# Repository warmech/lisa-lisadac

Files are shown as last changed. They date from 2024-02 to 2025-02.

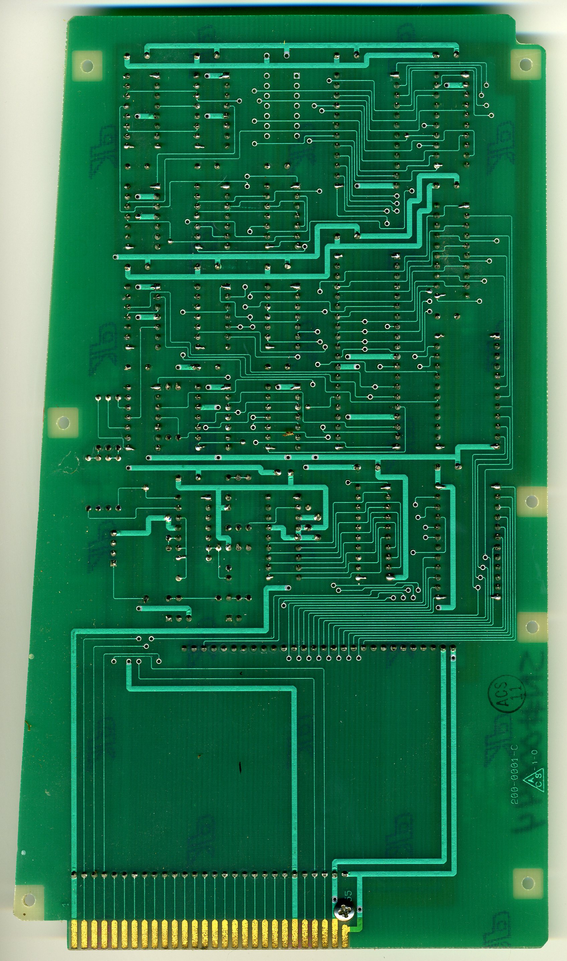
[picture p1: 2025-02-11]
neville_and_steele/NevilleAndSteele_LisaDAC_back.jpg

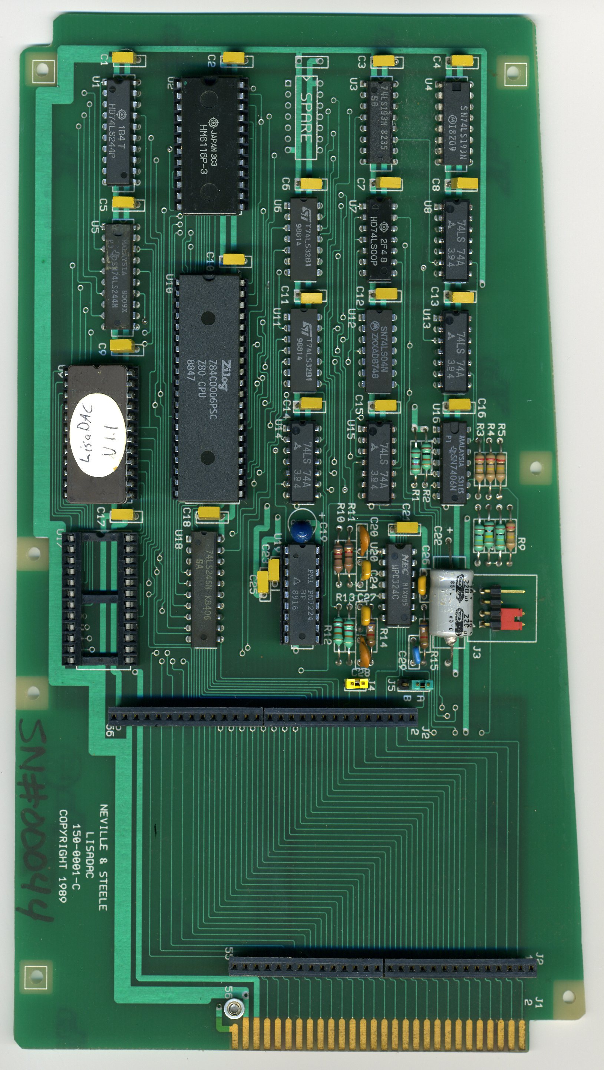
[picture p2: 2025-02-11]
neville_and_steele/NevilleAndSteele_LisaDAC_front.jpg

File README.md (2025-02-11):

# LisaDAC
 
This project aims to reproduce Neville & Steele's DAC expansion card for the Apple Lisa (via MacWorks) which provided audio functionality similar to the Macintosh sound hardware. The LisaDAC does not, however, produce 100% compatibility with Mac sound hardware and, as such, has a reduced/degraded audio output when compared to a Macintosh. In some cases, calls made in MacWorks to what would be the Mac's sound hardware when using a LisaDAC may result in MacOS/MacWorks crashing.

## Creator Commentary (10 February, 2025)

Daris A. Nevil, the original creator of this hardware, has generously provided some high-resolution scans and commentary on the history and design of this card. These can be found in the [neville_and_steele](neville_and_steele) directory in the root of this repository. Many thanks to Mr. Nevil for reaching out and providing these! It was a pleasure hearing from you.

## ROM Version

Both version 1.0 (v1_0.BIN) from the Neville & Steele card and 1.1 (v1_1.BIN) from the newer LDAC reproduction are included with this repository. These ROM dumps should be programmed on a 2716 EPROM or other compatible device.

## Jumper Settings

- J3 - Speaker Selection: To use the internal speaker, place a jumper on pins 3 and 4; to use an external speaker, connect the leads to pins 1 and 4.
- J4 - DMA Bus Grant Pass-Through: Whether or not this should have a jumper is debatable; no other Lisa expansion card uses DMA, so there aren't really any other DMA processes to interfere with. The stock configuration is to place a jumper across J4.
- J5 - Unknown: Likely has to do with card slot selection. Configuration "A" jumpers pins 1 and 2 and ties the /SHn (where n is 0, 1, or 2) line on the expansion bus to pin 9 of the 74LS00 at U7; configuration "B" jumpers pins 2 and 3 and ties the +5V rail to pin 9 of the 74LS00 at U7.

## Stability and Crashing

The LisaDAC is generally stable and does not cause stability issues in and of itself when used with a Lisa. Rather, the issue comes with Mac software making unsupported calls to the Mac's (well, MacWorks') sound hardware. StuntCopter, for instance, will run with no issues (albeit not sounding the best) until completing a successful round of five jumps. Upon completion of the fifth successful jump the victory chime is triggered; the call made to play the chime causes MacOS/MacWorks to immediately hang up, requiring either the reset button to be pressed or the Lisa's power to be cycled.

The following is a list of software with known incompatibilities with the LisaDAC:

- StuntCopter
	- Victory ("backflip") chime causes MacOS/MacWorks to crash

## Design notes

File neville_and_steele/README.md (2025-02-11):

# Neville & Steele version of LisaDAC

I have been interested in computer-generated sound at least since my freshman year in college. I began thinking about how to add sound output to my Lisa-XL computer. The Macintosh contained simple but effective four-channel sound generation. The Lisa-XL ran the same operating system, so I surmised that it might be possible to build hardware to work with the operating system software.

My friend Darryl Burrows had schematics and other technical documentation for the Lisa. After studying them I found some important features that assured my eventual success.

1. The Lisa provided three expansion slots.

2. It also supported DMA (Direct-Memory Access) from these slots to the system memory

3. The Lisa's built-in speaker was connected to each of the three slots

I designed and built a prototype circuit. It was hand-wired point-to-point. It worked well enough that I moved forward with the project. I outsourced the printed circuit board layout to a company down in Garland, Texas across Jupiter Road from Raytheon. The board layout had an unusual shape due to the sloping back of the Lisa, so it was nice to have a professional board shop do the layout and routing.

I worked with a small surplus electronics company on Bowser Road in Richardson, Texas.

Once we received the bare boards and the components, my wife Marianne and I set to work building the boards. We ordered 50 boards and enough parts to populate them all. I stuffed boards and Marianne did most of the soldering. She also debugged and repaired boards. (She can do just about anything!)

We sold about 30 of the boards. I tried to arrange to sell them through Sun Remarketing in Utah, but they were not interested. I finally contacted a company named DAFAX. They purchased the rights to the entire product. I don't know how many of them they sold, or if they made anymore boards. 
 
As you inspect the board you will notice two long connectors on the bottom half of the bottom half of the board. This is for lower-cost expansion (because making the specially shaped Lisa boards was more expensive). I designed and built a SCSI disk interface board. It leveraged the SCSI interface software that Sun Remarketing had put into the MacWorks Plus software. This may have been one of the reasons why Sun did not buy the board. They were already manufacturing a Lisa SCSI board and did not want a competitor. 

## Design

The board operated as follows. A 6116 static RAM was connected directly to the main Lisa 68000 CPU bus through the expansion connector. It served as a dual port RAM. The back half was also connected to an on-board Z80 CPU. The 68000 CPU was responsible for generating the sound values in a buffer on the RAM chip. The Z80 CPU ran a very small program that simply copied one byte at a time from the RAM and wrote it to a Digital-to-Analog Converter (DAC, hence LisaDAC). The analog output from the DAC was amplified by an LM324 operation amplifier (OPAMP) which drove the Lisa Speaker. The remainder of the TTL chips were used to control access to the 6116 static RAM between the 68000 and Z80 CPUs, as well as address decoding, etc. An on-board EPROM was also connected to the 68000 bus. It was read at power-up by the MacWorks Plus operating system to let the system know that the card was present.

A device driver was also required to be loaded in the MacWorks Plus operating system. It was responsible for setting up the Lisa's Memory Map Unit (MMU) to point to the 6116 static RAM in the proper slot where the LisaDAC was installed. The static RAM was mapped to the address of the main sound buffer, starting at address $7FD00 (refer to Inside Macintosh, Volume III, page 21). The driver also included the Z80 CPU's program. Upon power-up the Z80 CPU was held in reset, which prevented it from accessing the 6116. The 68000 loaded the Z80 program into a reserved section of the 6116 RAM, then wrote to an address that released the Z80 from reset, which allowed the Z80 to run its program from the static RAM.

The Z80 CPU used the Direct Memory Access (DMA) lines to gain access to the 68000 bus in order to read bytes from the SRAM.

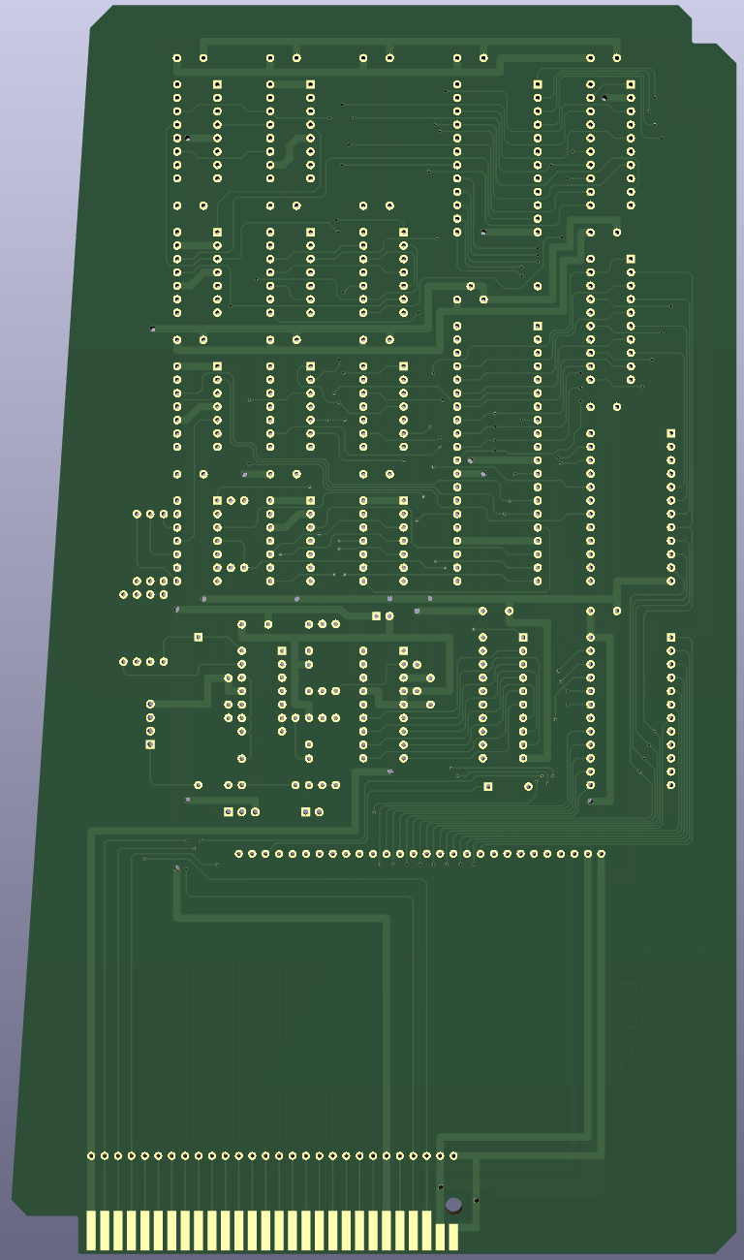
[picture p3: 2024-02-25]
images/pcb_rear_render.png

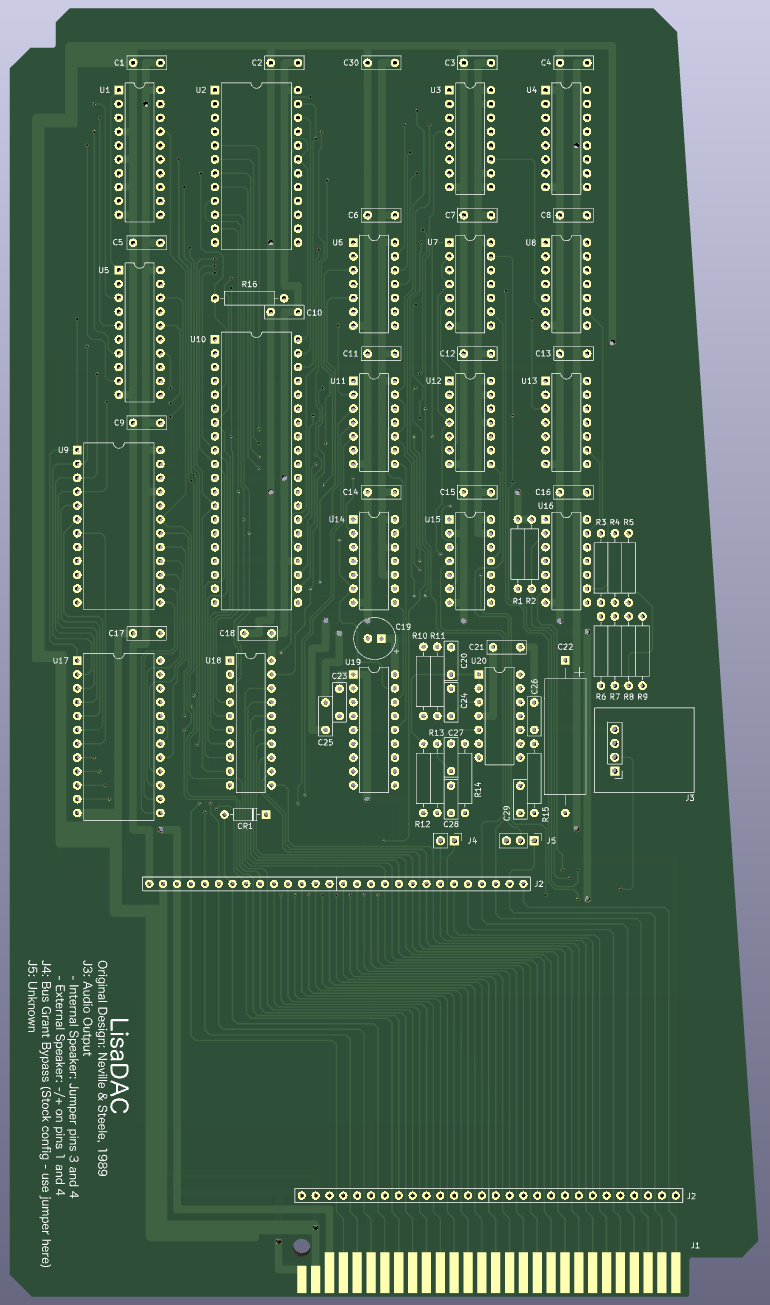
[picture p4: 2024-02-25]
images/pcb_front_render.png

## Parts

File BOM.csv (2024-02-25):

# | Reference | Qty | Value | Footprint | DNP
1 | C1, C2, C3, C4, C5, C6, C7, C8, C9, C10, C11, C12, C13, C14, C15, C16, C17, C18, C21, C23, C25 | 21 | 0.1uF 50V | Capacitor_THT_Custom:C_Disc_D7.0mm_W2.3mm_P5.00mm
2 | C19 | 1 | 10uF 35V | Capacitor_THT_Custom:CP_Radial_D7.8mm_P2.50mm
3 | C20, C28 | 2 | 0.01uF 1KV | Capacitor_THT_Custom:C_Disc_D7.0mm_W2.3mm_P5.00mm
4 | C22 | 1 | 220uF / 16V | Capacitor_THT_Custom:CP_Axial_L21.0mm_D7.6mm_P28.00mm_Horizontal
5 | C24, C26, C27, C29 | 4 | 4.7nF 50V | Capacitor_THT_Custom:C_Disc_D7.0mm_W2.3mm_P5.00mm
6 | C30 | 1 | 330uF / 25V | Capacitor_THT_Custom:C_Disc_D7.0mm_W2.3mm_P5.00mm
7 | CR1 | 1 | 1N4148 | Diode_THT:D_DO-35_SOD27_P7.62mm_Horizontal
8 | J3 | 1 | Audio Connector | Connector_PinHeader_2.54mm:PinHeader_1x04_P2.54mm_Vertical
9 | J4 | 1 | Bus Grant Bypass | Connector_PinHeader_2.54mm:PinHeader_1x02_P2.54mm_Vertical
10 | J5 | 1 | High ROM Select | Connector_PinHeader_2.54mm:PinHeader_1x03_P2.54mm_Vertical
11 | R1, R2, R16 | 3 | 1K | Resistor_THT_Custom:R_Axial_DIN0309_L9.0mm_D2.54mm_P12.70mm_Horizontal
12 | R3, R4, R6, R7, R8 | 5 | 100K | Resistor_THT_Custom:R_Axial_DIN0309_L9.0mm_D2.54mm_P12.70mm_Horizontal
13 | R5, R9 | 2 | 200K | Resistor_THT_Custom:R_Axial_DIN0309_L9.0mm_D2.54mm_P12.70mm_Horizontal
14 | R10, R11, R12, R13, R14, R15 | 6 | 6.8K | Resistor_THT_Custom:R_Axial_DIN0309_L9.0mm_D2.54mm_P12.70mm_Horizontal
15 | U1, U5 | 2 | 74LS244 | Package_DIP:DIP-20_W7.62mm
16 | U2 | 1 | 6116 | Package_DIP:DIP-24_W15.24mm
17 | U3, U4 | 2 | 74LS193 | Package_DIP:DIP-16_W7.62mm
18 | U6, U11 | 2 | 74LS32 | Package_DIP:DIP-14_W7.62mm
19 | U7 | 1 | 74LS00 | Package_DIP:DIP-14_W7.62mm
20 | U8, U13, U14, U15 | 4 | 74LS74 | Package_DIP:DIP-14_W7.62mm
21 | U9, U17 | 2 | 2716 | Package_DIP:DIP-24_W15.24mm
22 | U10 | 1 | Z80CPU | Package_DIP:DIP-40_W15.24mm
23 | U12 | 1 | 74LS04 | Package_DIP:DIP-14_W7.62mm
24 | U16 | 1 | 7406 | Package_DIP:DIP-14_W7.62mm
25 | U18 | 1 | 74LS245 | Package_DIP:DIP-20_W7.62mm
26 | U19 | 1 | AD7224LN | Package_DIP:DIP-18_W7.62mm
27 | U20 | 1 | LM324 | Package_DIP:DIP-14_W7.62mm

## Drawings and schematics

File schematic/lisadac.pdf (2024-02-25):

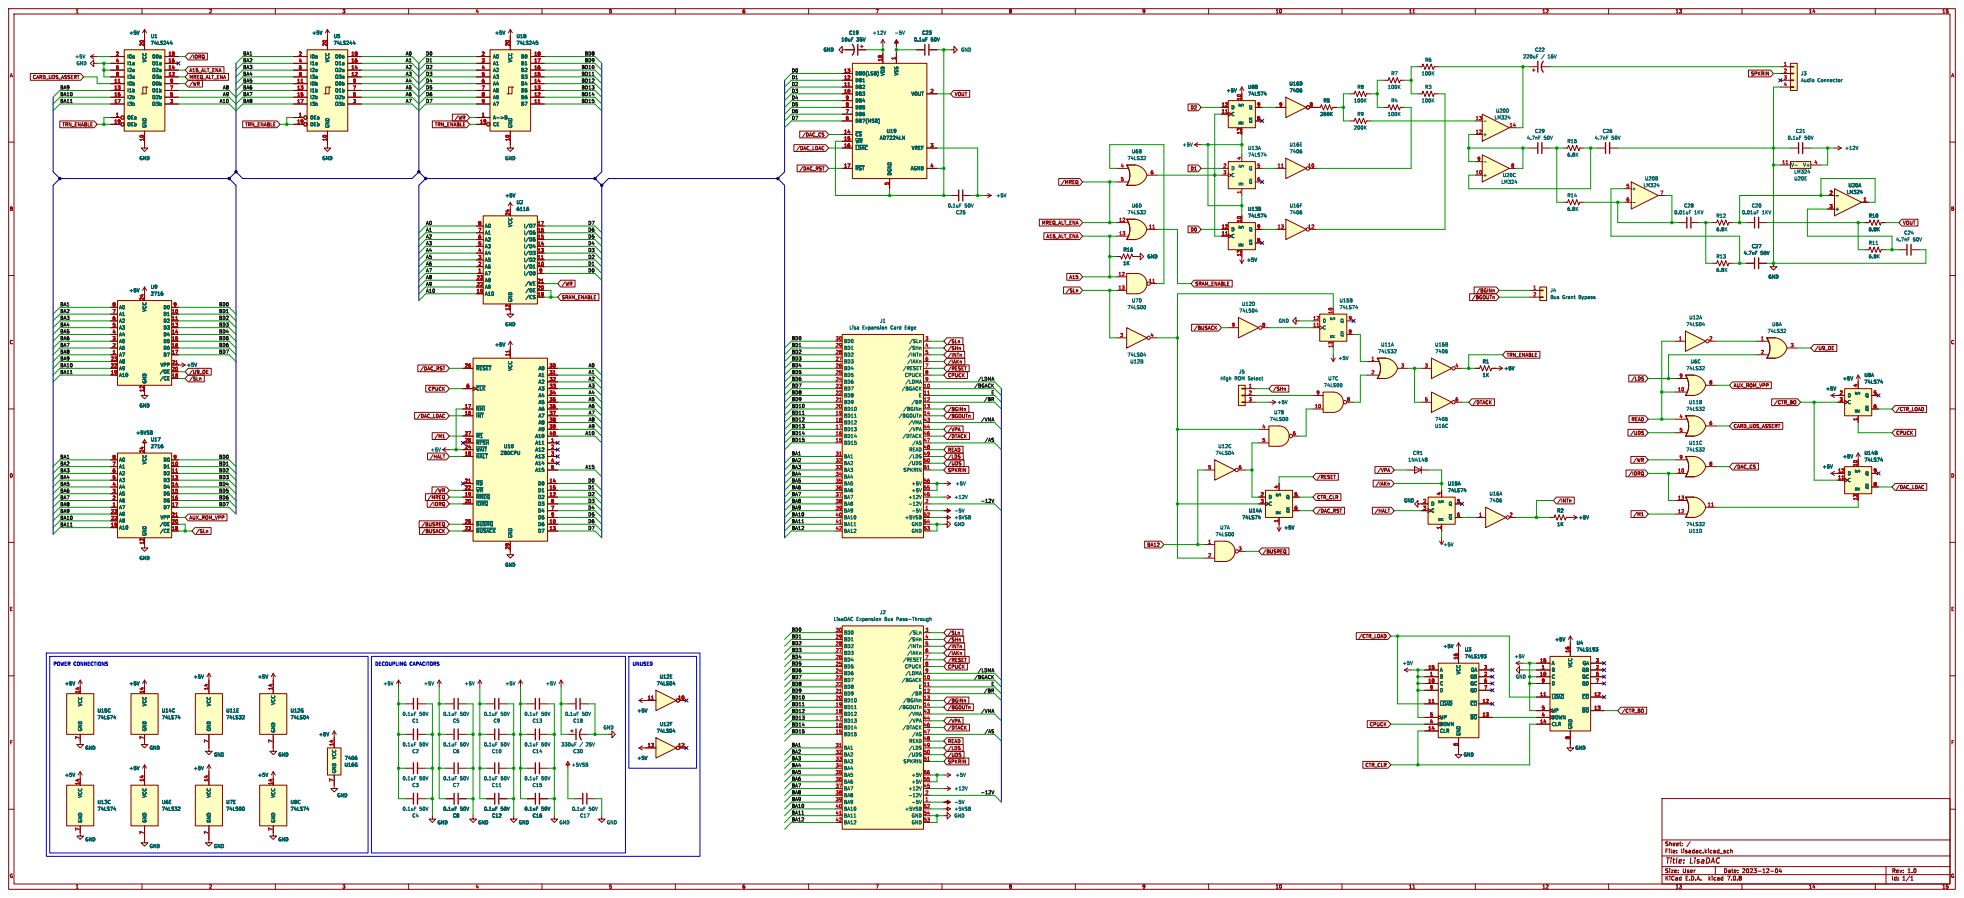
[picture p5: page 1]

1 DB3 10 DB2 11 DB1 12 DB0(LSB) 13 ~{CS} 14 ~{WR} 15 ~{LDAC} 16 ~{RST} 17 VDD 18 VOUT

Lisa Expansion Card Edge GND

74LS74 GND GND VCC 14 GND

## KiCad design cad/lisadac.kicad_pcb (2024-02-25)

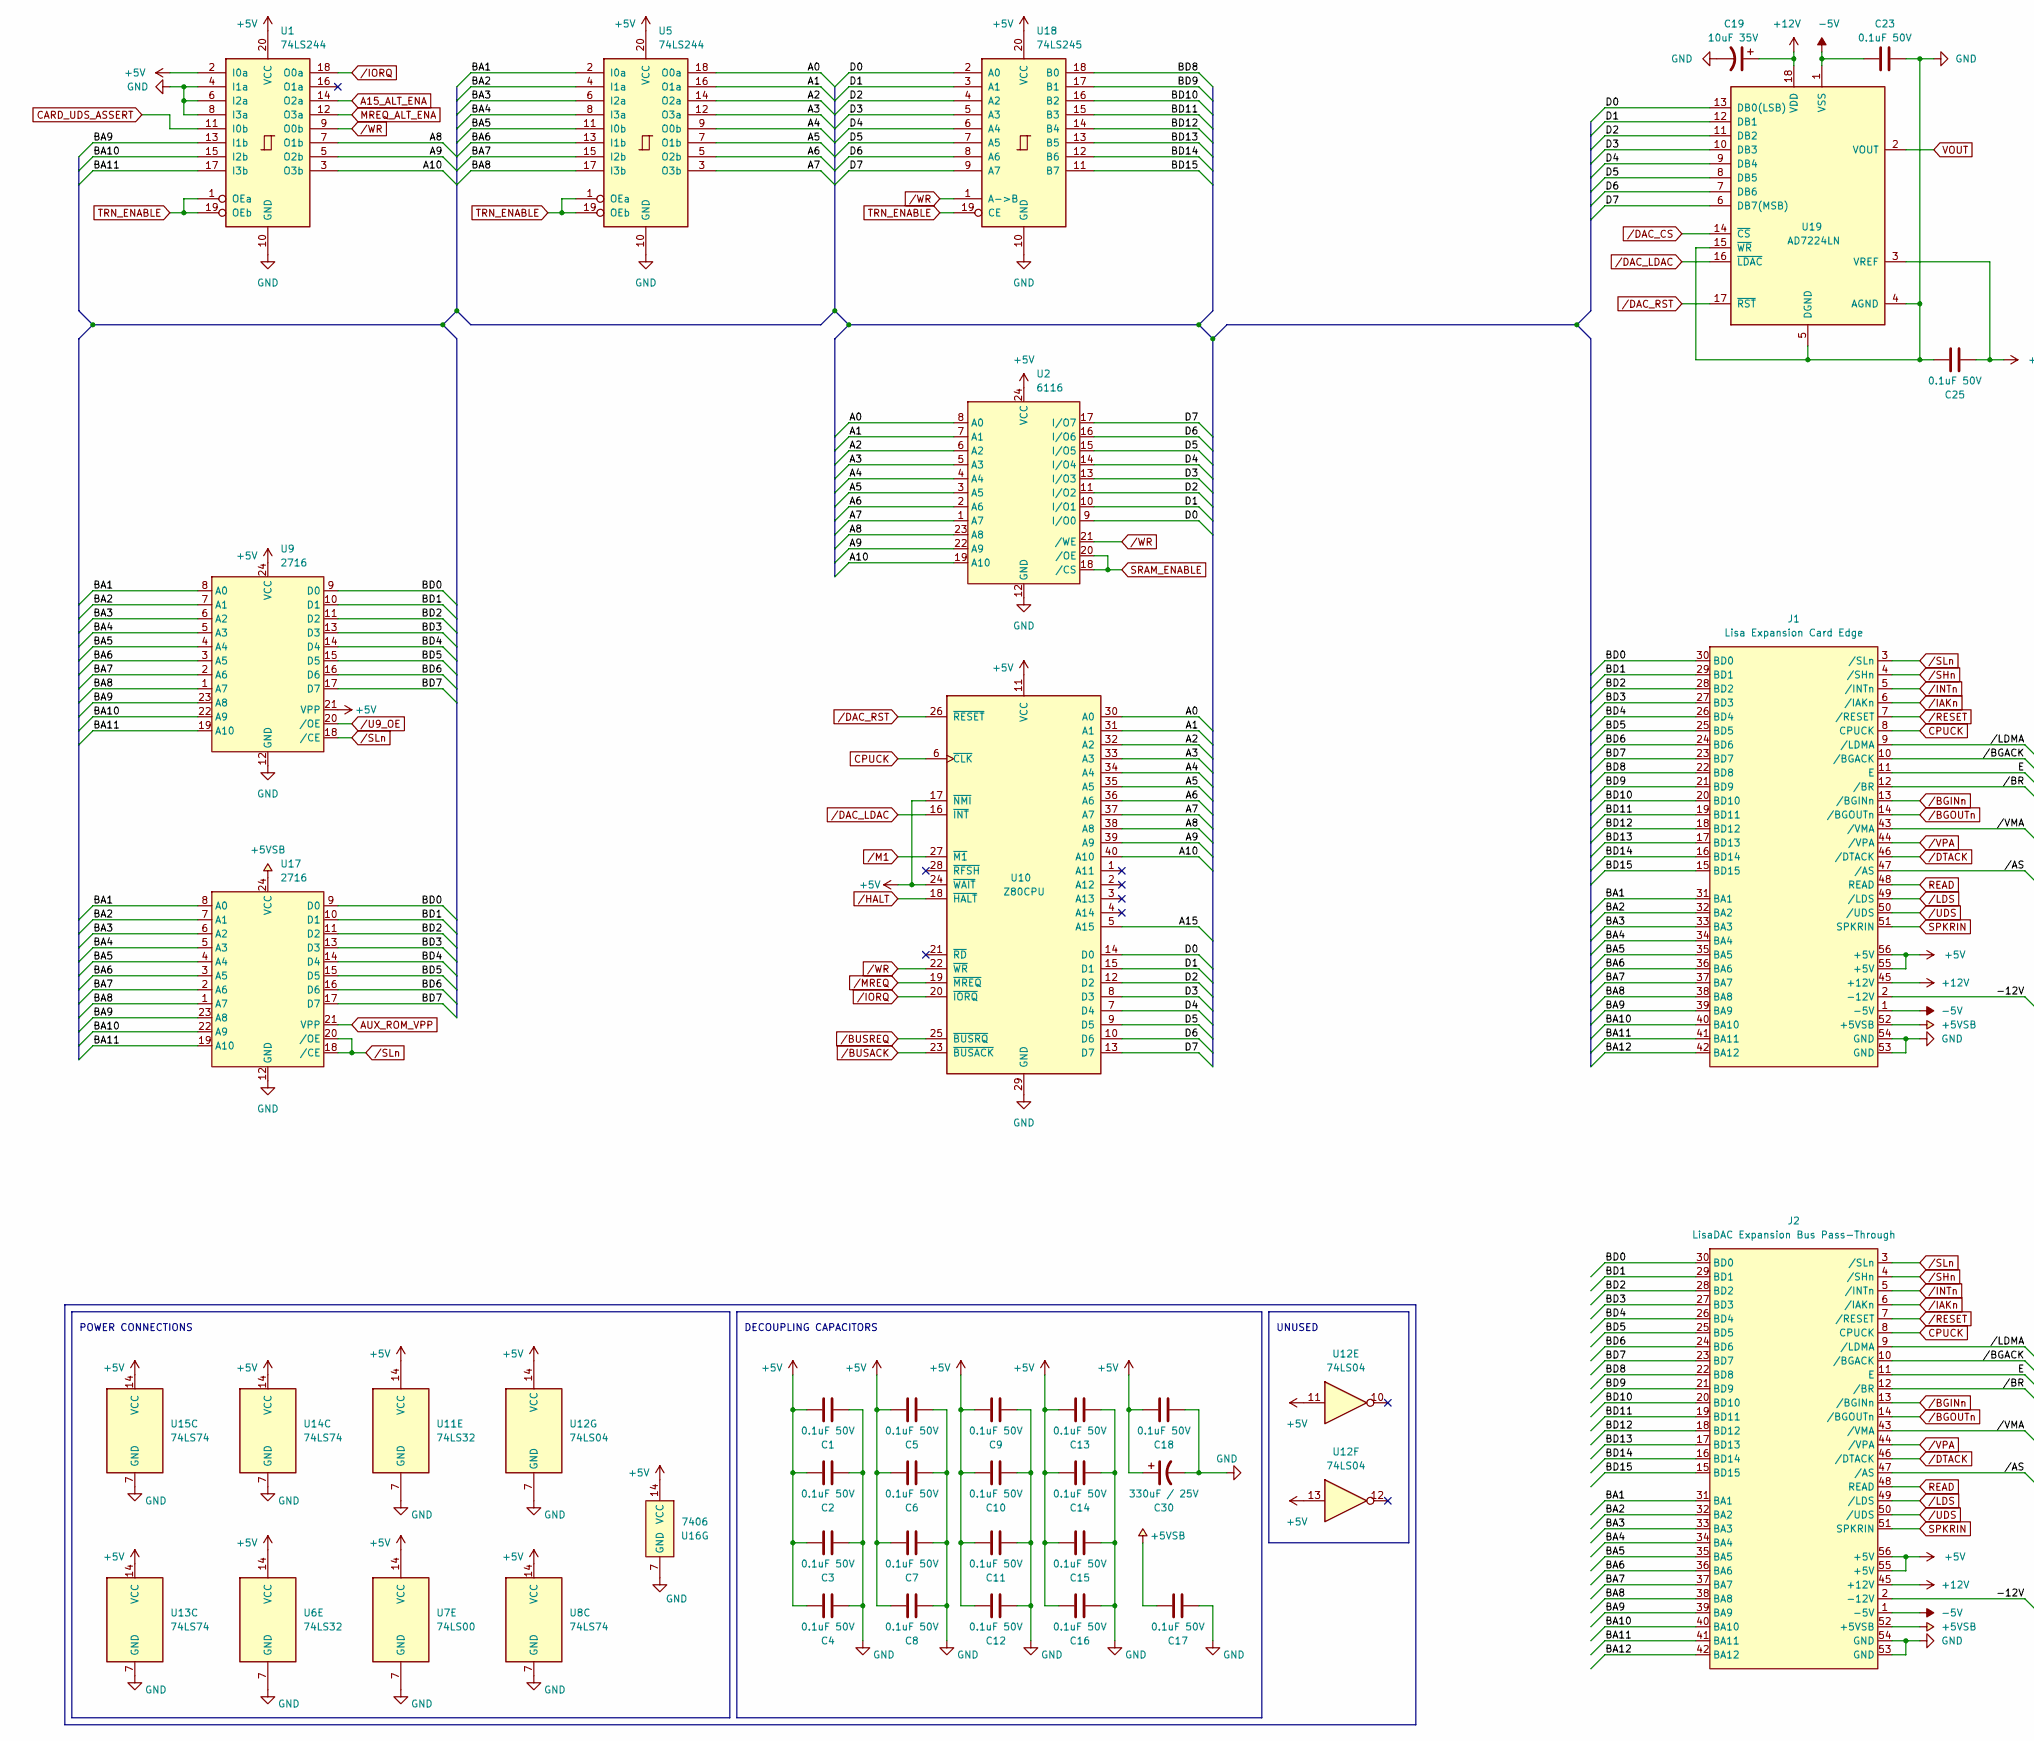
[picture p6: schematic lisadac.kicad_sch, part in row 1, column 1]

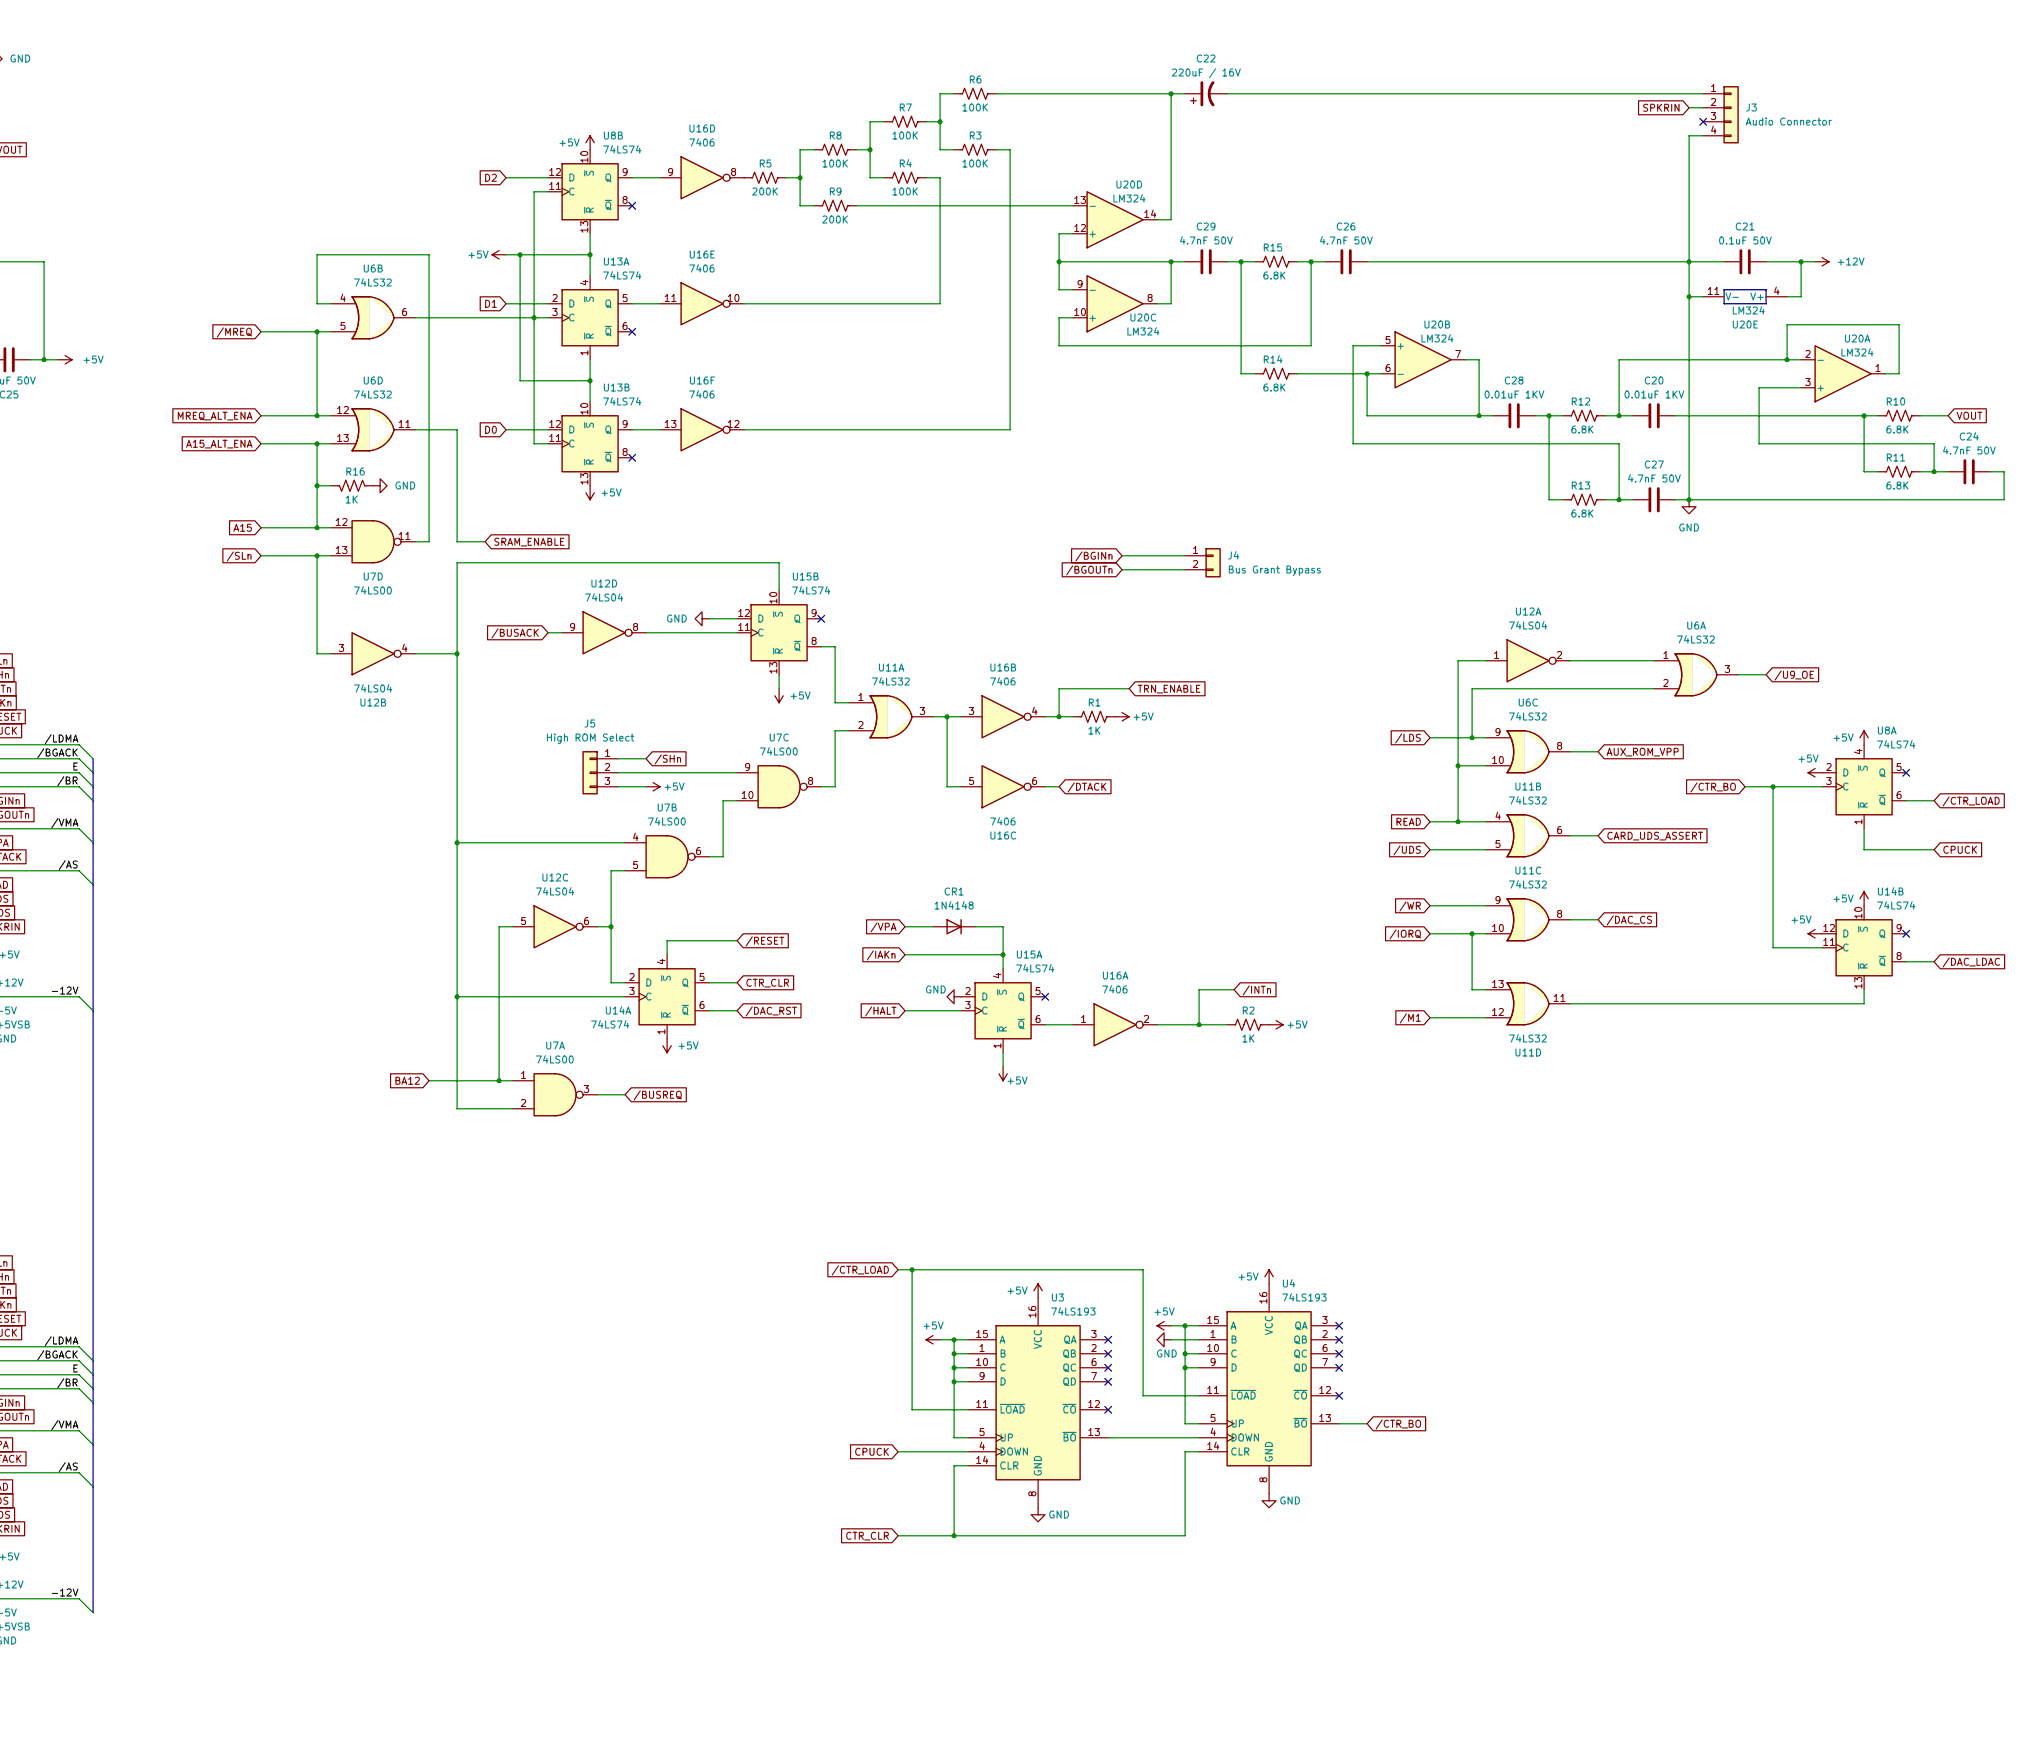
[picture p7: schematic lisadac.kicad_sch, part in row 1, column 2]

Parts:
C1, C2, C3, C4, C5, C6, C7, C8, C9, C10, C11, C12, C13, C14, C15, C16, C17, C18, C21, C23, C25: 0.1uF 50V; C_Disc_D7.0mm_W2.3mm_P5.00mm
C19: 10uF 35V; CP_Radial_D7.8mm_P2.50mm
C20, C28: 0.01uF 1KV; C_Disc_D7.0mm_W2.3mm_P5.00mm
C22: 220uF / 16V; CP_Axial_L21.0mm_D7.6mm_P28.00mm_Horizontal
C24, C26, C27, C29: 4.7nF 50V; C_Disc_D7.0mm_W2.3mm_P5.00mm
C30: 330uF / 25V; C_Disc_D7.0mm_W2.3mm_P5.00mm
CR1: 1N4148; D_DO-35_SOD27_P7.62mm_Horizontal
J1: Lisa Expansion Card Edge; Apple_Lisa_ExpansionBus_CardEdge
J2: LisaDAC Expansion Bus Pass-Through; Apple_Lisa_LisaDAC_ExpansionBus_PassThrough
J3: Audio Connector; PinHeader_1x04_P2.54mm_Vertical
J4: Bus Grant Bypass; PinHeader_1x02_P2.54mm_Vertical
J5: High ROM Select; PinHeader_1x03_P2.54mm_Vertical
R1, R2, R16: 1K; R_Axial_DIN0309_L9.0mm_D2.54mm_P12.70mm_Horizontal
R3, R4, R6, R7, R8: 100K; R_Axial_DIN0309_L9.0mm_D2.54mm_P12.70mm_Horizontal
R5, R9: 200K; R_Axial_DIN0309_L9.0mm_D2.54mm_P12.70mm_Horizontal
R10, R11, R12, R13, R14, R15: 6.8K; R_Axial_DIN0309_L9.0mm_D2.54mm_P12.70mm_Horizontal
U1, U5: 74LS244; DIP-20_W7.62mm
U2: 6116; DIP-24_W15.24mm
U3, U4: 74LS193; DIP-16_W7.62mm
U6, U11: 74LS32; DIP-14_W7.62mm
U7: 74LS00; DIP-14_W7.62mm
U8, U13, U14, U15: 74LS74; DIP-14_W7.62mm
U9, U17: 2716; DIP-24_W15.24mm
U10: Z80CPU; DIP-40_W15.24mm
U12: 74LS04; DIP-14_W7.62mm
U16: 7406; DIP-14_W7.62mm
U18: 74LS245; DIP-20_W7.62mm
U19: AD7224LN; DIP-18_W7.62mm
U20: LM324; DIP-14_W7.62mm

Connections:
+5V: C1.2, C2.2, C3.2, C4.2, C5.2, C6.2, C7.2, C8.2, C9.2, C10.2, C11.2, C12.2, C13.2, C14.2, C15.2, C16.2, C18.2, C25.2, C30.1, J1.55 (+5V), J1.56 (+5V), J2.55 (+5V), J2.56 (+5V), J5.3, R1.1, R2.1, U1.2 (I0a), U1.20 (VCC), U2.24 (VCC), U3.1 (B), U3.5 (UP), U3.9 (D), U3.10 (C), U3.15 (A), U3.16 (VCC), U4.5 (UP), U4.9 (D), U4.10 (C), U4.15 (A), U4.16 (VCC), U5.20 (VCC), U6.14 (VCC), U7.14 (VCC), U8.2 (D), U8.4 (~S), U8.10 (~S), U8.13 (~R), U8.14 (VCC), U9.21 (VPP), U9.24 (VCC), U10.11 (VCC), U10.17 (~NMI), U10.24 (~WAIT), U11.14 (VCC), U12.11, U12.13, U12.14 (VCC), U13.1 (~R), U13.4 (~S), U13.10 (~S), U13.13 (~R), U13.14 (VCC), U14.1 (~R), U14.10 (~S), U14.12 (D), U14.14 (VCC), U15.1 (~R), U15.13 (~R), U15.14 (VCC), U16.14 (VCC), U18.20 (VCC), U19.3 (VREF)
+12V: C19.1, C21.1, J1.45 (+12V), J2.45 (+12V), U19.18 (VDD), U20.4 (V+)
-5V: C23.2, J1.1 (-5V), J2.1 (-5V), U19.1 (VSS)
-15V: C17.2, J1.52 (+5VSB), J2.52 (+5VSB), U17.24 (VCC)
/-12V: J1.2 (-12V), J2.2 (-12V)
/A0: U2.8 (A0), U5.18 (O0a), U10.30 (A0)
/A1: U2.7 (A1), U5.16 (O1a), U10.31 (A1)
/A2: U2.6 (A2), U5.14 (O2a), U10.32 (A2)
/A3: U2.5 (A3), U5.12 (O3a), U10.33 (A3)
/A4: U2.4 (A4), U5.9 (O0b), U10.34 (A4)
/A5: U2.3 (A5), U5.7 (O1b), U10.35 (A5)
/A6: U2.2 (A6), U5.5 (O2b), U10.36 (A6)
/A7: U2.1 (A7), U5.3 (O3b), U10.37 (A7)
/A8: U1.7 (O1b), U2.23 (A8), U10.38 (A8)
/A9: U1.5 (O2b), U2.22 (A9), U10.39 (A9)
/A10: U1.3 (O3b), U2.19 (A10), U10.40 (A10)
/BA1: J1.31 (BA1), J2.31 (BA1), U5.2 (I0a), U9.8 (A0), U17.8 (A0)
/BA2: J1.32 (BA2), J2.32 (BA2), U5.4 (I1a), U9.7 (A1), U17.7 (A1)
/BA3: J1.33 (BA3), J2.33 (BA3), U5.6 (I2a), U9.6 (A2), U17.6 (A2)
/BA4: J1.34 (BA4), J2.34 (BA4), U5.8 (I3a), U9.5 (A3), U17.5 (A3)
/BA5: J1.35 (BA5), J2.35 (BA5), U5.11 (I0b), U9.4 (A4), U17.4 (A4)
/BA6: J1.36 (BA6), J2.36 (BA6), U5.13 (I1b), U9.3 (A5), U17.3 (A5)
/BA7: J1.37 (BA7), J2.37 (BA7), U5.15 (I2b), U9.2 (A6), U17.2 (A6)
/BA8: J1.38 (BA8), J2.38 (BA8), U5.17 (I3b), U9.1 (A7), U17.1 (A7)
/BA9: J1.39 (BA9), J2.39 (BA9), U1.13 (I1b), U9.23 (A8), U17.23 (A8)
/BA10: J1.40 (BA10), J2.40 (BA10), U1.15 (I2b), U9.22 (A9), U17.22 (A9)
/BA11: J1.41 (BA11), J2.41 (BA11), U1.17 (I3b), U9.19 (A10), U17.19 (A10)
/BD0: J1.30 (BD0), J2.30 (BD0), U9.9 (D0), U17.9 (D0)
/BD1: J1.29 (BD1), J2.29 (BD1), U9.10 (D1), U17.10 (D1)
/BD2: J1.28 (BD2), J2.28 (BD2), U9.11 (D2), U17.11 (D2)
/BD3: J1.27 (BD3), J2.27 (BD3), U9.13 (D3), U17.13 (D3)
/BD4: J1.26 (BD4), J2.26 (BD4), U9.14 (D4), U17.14 (D4)
/BD5: J1.25 (BD5), J2.25 (BD5), U9.15 (D5), U17.15 (D5)
/BD6: J1.24 (BD6), J2.24 (BD6), U9.16 (D6), U17.16 (D6)
/BD7: J1.23 (BD7), J2.23 (BD7), U9.17 (D7), U17.17 (D7)
/BD8: J1.22 (BD8), J2.22 (BD8), U18.18 (B0)
/BD9: J1.21 (BD9), J2.21 (BD9), U18.17 (B1)
/BD10: J1.20 (BD10), J2.20 (BD10), U18.16 (B2)
/BD11: J1.19 (BD11), J2.19 (BD11), U18.15 (B3)
/BD12: J1.18 (BD12), J2.18 (BD12), U18.14 (B4)
/BD13: J1.17 (BD13), J2.17 (BD13), U18.13 (B5)
/BD14: J1.16 (BD14), J2.16 (BD14), U18.12 (B6)
/BD15: J1.15 (BD15), J2.15 (BD15), U18.11 (B7)
/D3: U2.13 (I/O3), U10.8 (D3), U18.5 (A3), U19.10 (DB3)
/D4: U2.14 (I/O4), U10.7 (D4), U18.6 (A4), U19.9 (DB4)
/D5: U2.15 (I/O5), U10.9 (D5), U18.7 (A5), U19.8 (DB5)
/D6: U2.16 (I/O6), U10.10 (D6), U18.8 (A6), U19.7 (DB6)
/D7: U2.17 (I/O7), U10.13 (D7), U18.9 (A7), U19.6 (DB7(MSB))
/E: J1.11 (E), J2.11 (E)
//AS: J1.47 (/AS), J2.47 (/AS)
//BGACK: J1.10 (/BGACK), J2.10 (/BGACK)
//BR: J1.12 (/BR), J2.12 (/BR)
//LDMA: J1.9 (/LDMA), J2.9 (/LDMA)
//VMA: J1.43 (/VMA), J2.43 (/VMA)
A15: R16.1, U1.14 (O2a), U6.13, U7.12, U10.5 (A15)
AUX_ROM_VPP: U6.8, U17.21 (VPP)
BA12: J1.42 (BA12), J2.42 (BA12), U7.1, U12.5
CARD_UDS_ASSERT: U1.11 (I0b), U11.6
CPUCK: J1.8 (CPUCK), J2.8 (CPUCK), U3.4 (DOWN), U8.1 (~R), U10.6 (~CLK)
CTR_CLR: U3.14 (CLR), U4.14 (CLR), U14.5 (Q)
D0: U2.9 (I/O0), U10.14 (D0), U13.12 (D), U18.2 (A0), U19.13 (DB0(LSB))
D1: U2.10 (I/O1), U10.15 (D1), U13.2 (D), U18.3 (A1), U19.12 (DB1)
D2: U2.11 (I/O2), U8.12 (D), U10.12 (D2), U18.4 (A2), U19.11 (DB2)
GND: C1.1, C2.1, C3.1, C4.1, C5.1, C6.1, C7.1, C8.1, C9.1, C10.1, C11.1, C12.1, C13.1, C14.1, C15.1, C16.1, C17.1, C18.1, C19.2, C21.2, C23.1, C24.2, C25.1, C26.2, C27.1, C30.2, J1.53 (GND), J1.54 (GND), J2.53 (GND), J2.54 (GND), J3.4, R16.2, U1.4 (I1a), U1.6 (I2a), U1.8 (I3a), U1.10 (GND), U2.12 (GND), U3.8 (GND), U4.1 (B), U4.8 (GND), U5.10 (GND), U6.7 (GND), U7.7 (GND), U8.7 (GND), U9.12 (GND), U10.29 (GND), U11.7 (GND), U12.7 (GND), U13.7 (GND), U14.7 (GND), U15.2 (D), U15.7 (GND), U15.12 (D), U16.7 (GND), U17.12 (GND), U18.10 (GND), U19.4 (AGND), U19.5 (DGND), U19.15 (~WR), U20.11 (V-)
MREQ_ALT_ENA: U1.12 (O3a), U6.5, U6.12, U10.19 (~MREQ)
unnamed: C20.2, R10.2, R11.2
unnamed: C22.1, R6.1, U20.14
unnamed: C28.2, R12.2, R13.2
unnamed: C29.2, R14.2, R15.2
unnamed: C22.2, J3.1
unnamed: J5.2, U7.9
unnamed: R3.1, U16.12
unnamed: R3.2, R6.2, R7.1
unnamed: R4.1, U16.10
unnamed: R4.2, R7.2, R8.1
unnamed: R5.1, R8.2, R9.2
unnamed: R5.2, U16.8
unnamed: U3.13 (~BO), U4.4 (DOWN)
unnamed: U6.4, U7.11
unnamed: U7.6, U7.10
unnamed: U8.9 (Q), U16.9
unnamed: U7.8, U11.2
unnamed: U11.3, U16.3, U16.5
unnamed: U6.1, U12.2
unnamed: U6.6, U8.11 (C), U13.3 (C), U13.11 (C)
unnamed: U13.5 (Q), U16.11
unnamed: U13.9 (Q), U16.13
unnamed: U7.2, U7.4, U12.4, U14.3 (C), U15.10 (~S)
unnamed: U7.5, U12.6, U14.2 (D)
unnamed: U11.11, U14.13 (~R)
unnamed: U15.6 (~Q), U16.1
unnamed: U12.8, U15.11 (C)
unnamed: U11.1, U15.8 (~Q)
unnamed: C24.1, R11.1, U20.3 (+)
unnamed: C20.1, R12.1, U20.1, U20.2 (-)
unnamed: C27.2, R13.1, U20.5 (+)
unnamed: C28.1, R14.1, U20.6 (-), U20.7
unnamed: C26.1, R15.1, U20.10 (+)
unnamed: C29.1, U20.8, U20.9 (-), U20.12 (+)
unnamed: R9.1, U20.13 (-)
READ: J1.48 (READ), J2.48 (READ), U6.10, U11.4, U12.1
SPKRIN: J1.51 (SPKRIN), J2.51 (SPKRIN), J3.2
SRAM_ENABLE: U2.18 (/CS), U2.20 (/OE), U6.11
TRN_ENABLE: R1.2, U1.1 (OEa), U1.19 (OEb), U5.1 (OEa), U5.19 (OEb), U16.4, U18.19 (CE)
VOUT: R10.1, U19.2 (VOUT)
/BGINn: J1.13 (/BGINn), J2.13 (/BGINn), J4.1
/BGOUTn: J1.14 (/BGOUTn), J2.14 (/BGOUTn), J4.2
/BUSACK: U10.23 (~BUSACK), U12.9
/BUSREQ: U7.3, U10.25 (~BUSRQ)
/CTR_BO: U4.13 (~BO), U8.3 (C), U14.11 (C)
/CTR_LOAD: U3.11 (~LOAD), U4.11 (~LOAD), U8.6 (~Q)
/DAC_CS: U11.8, U19.14 (~CS)
/DAC_LDAC: U10.16 (~INT), U14.8 (~Q), U19.16 (~LDAC)
/DAC_RST: U10.26 (~RESET), U14.6 (~Q), U19.17 (~RST)
/DTACK: J1.46 (/DTACK), J2.46 (/DTACK), U16.6
/HALT: U10.18 (~HALT), U15.3 (C)
/IAKn: CR1.1 (K), J1.6 (/IAKn), J2.6 (/IAKn), U15.4 (~S)
/INTn: J1.5 (/INTn), J2.5 (/INTn), R2.2, U16.2
/IORQ: U1.18 (O0a), U10.20 (~IORQ), U11.10, U11.13
/LDS: J1.49 (/LDS), J2.49 (/LDS), U6.2, U6.9
/M1: U10.27 (~M1), U11.12
/RESET: J1.7 (/RESET), J2.7 (/RESET), U14.4 (~S)
/SHn: J1.4 (/SHn), J2.4 (/SHn), J5.1
/SLn: J1.3 (/SLn), J2.3 (/SLn), U7.13, U9.18 (/CE), U12.3, U17.18 (/CE), U17.20 (/OE)
/U9_OE: U6.3, U9.20 (/OE)
/UDS: J1.50 (/UDS), J2.50 (/UDS), U11.5
/VPA: CR1.2 (A), J1.44 (/VPA), J2.44 (/VPA)
/WR: U1.9 (O0b), U2.21 (/WE), U10.22 (~WR), U11.9, U18.1 (A->B)

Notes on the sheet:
POWER CONNECTIONS
UNUSED
DECOUPLING CAPACITORS

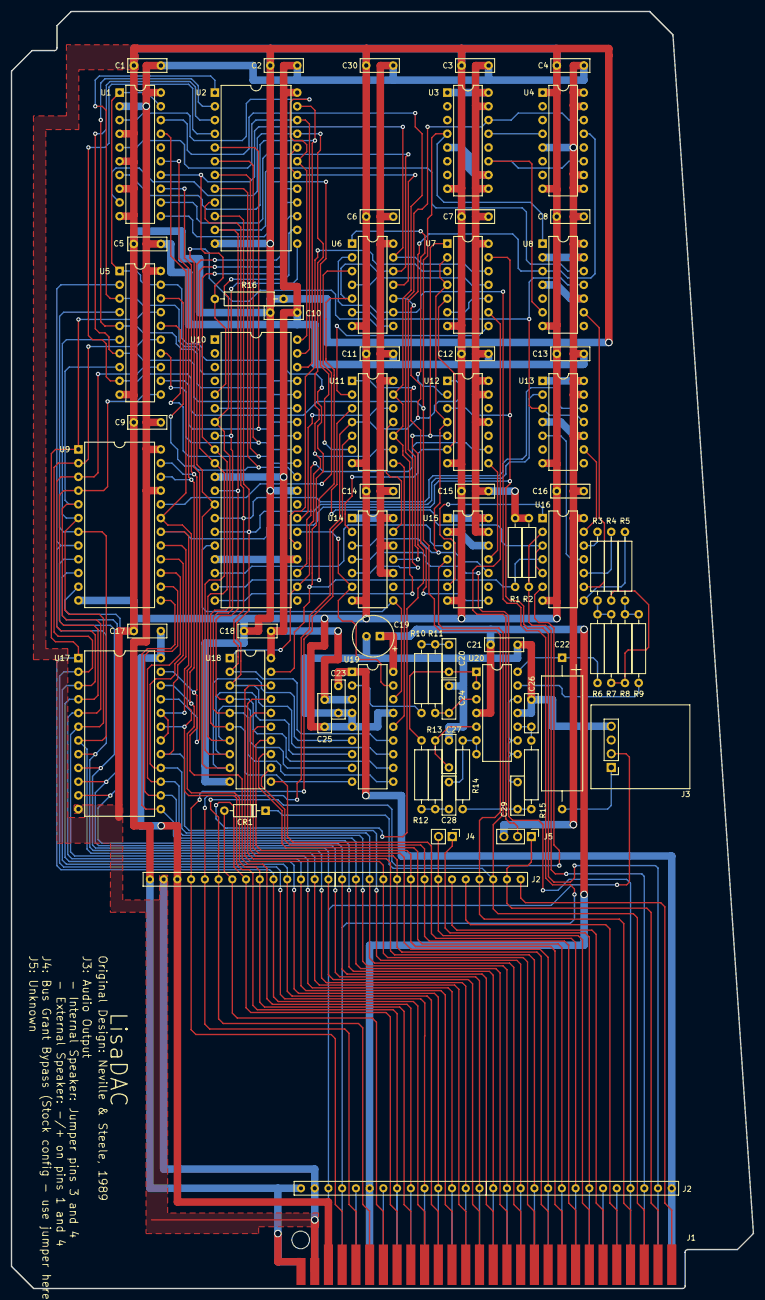
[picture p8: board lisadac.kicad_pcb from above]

Board: 2 copper layers, 137.2 x 236.2 mm, 72 parts (0 on the bottom side), 128 nets.
